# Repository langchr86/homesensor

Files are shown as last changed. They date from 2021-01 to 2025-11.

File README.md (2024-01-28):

homesensor
==========



Air quality sensor designed for battery operation and central data collection in HomeAssistant.

Introduction
------------

This project contains all things needed to setup e.g. a sensor grid for monitoring
temperature, humidity and CO2-levels in several rooms in your home and maybe outside.

The sensors are built from scratch with an `ESP32` as compute unit
and a sensirion `SHTC3` for temperature and humidity monitoring.
For additional CO2-level measurement a sensirion `SCD30` can be used.
The software is based on `platform-io` and is therefore easy to build and deploy.

The sensor data is sent via W-LAN and MQTT protocol to `home assistant` on the backend server.
Home assistant is at first place a home automation system.
But one part of automation is to collect data from sensors.
We therefore use this mechanisms and the corresponding Web-UI
to have a flexible way to store and visualize the collected data.

A very similar but more generic project is [ESPHome](https://esphome.io/)

Getting started
---------------

The whole project consists of the following parts:

* [Backend Software](backend/)
* [Hardware](hardware/)
* [Device Software](software/)

See the linked sub-pages for further instructions.

Usage
-----

<p float="left">
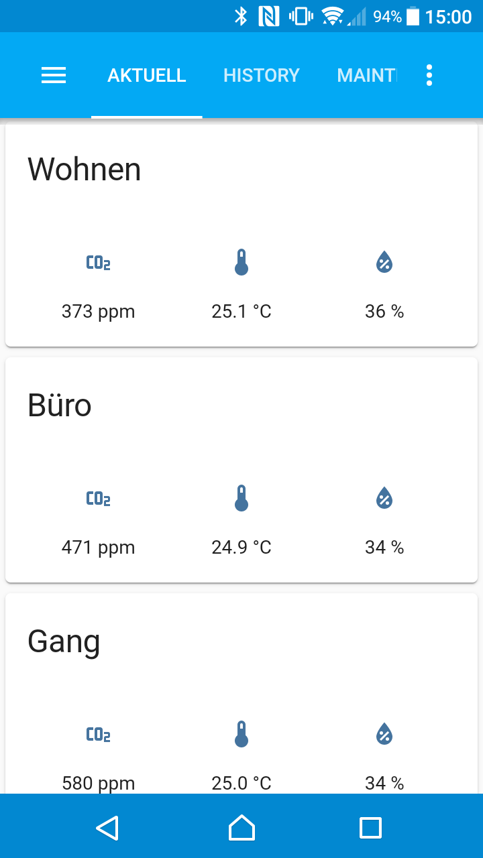
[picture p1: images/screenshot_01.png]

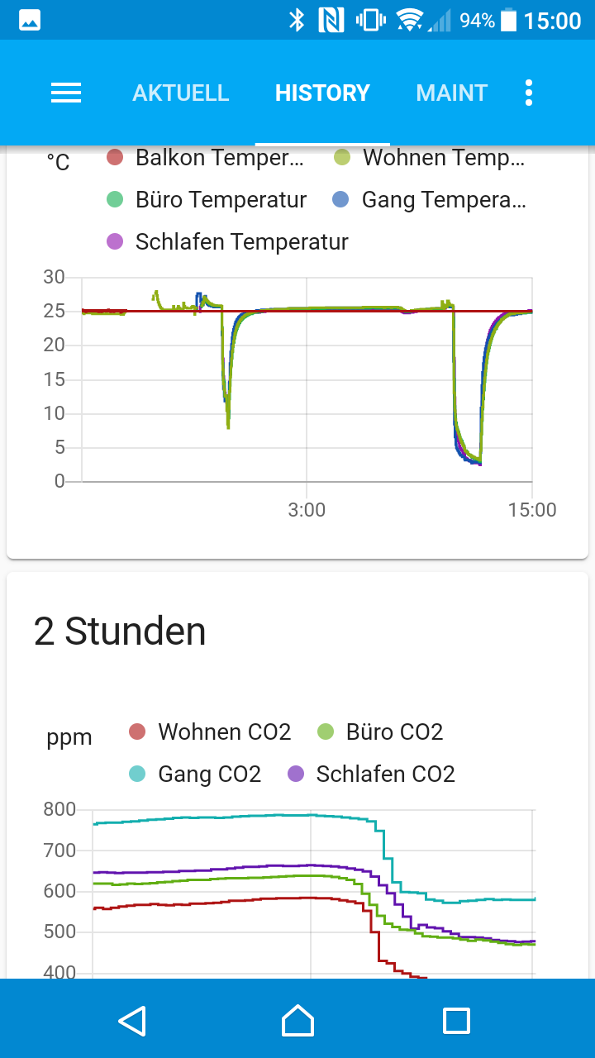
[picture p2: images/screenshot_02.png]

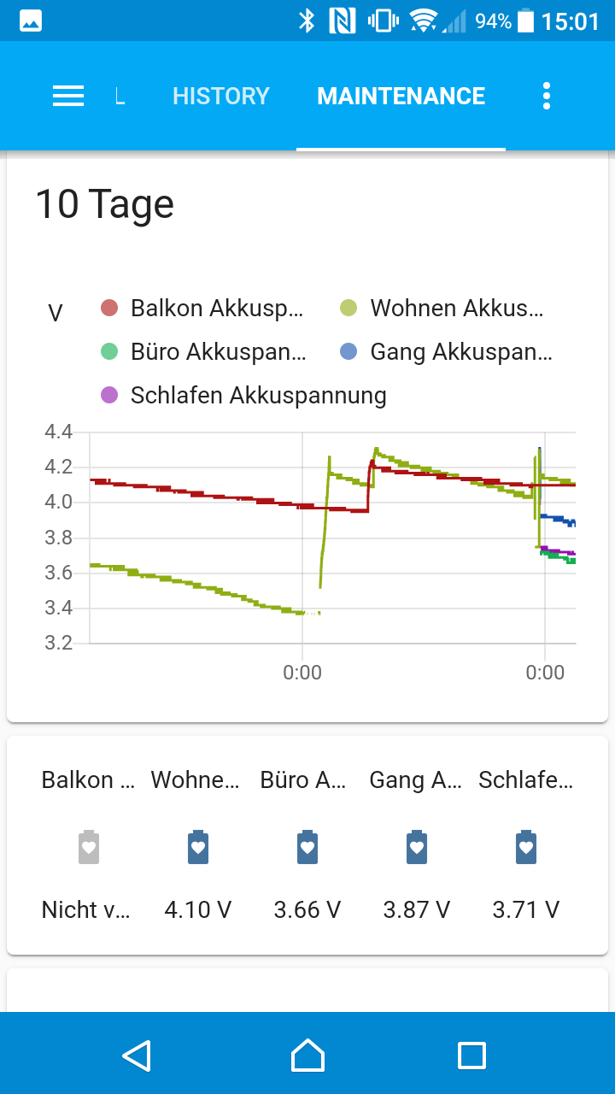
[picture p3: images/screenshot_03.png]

</p>

### Indoor - SCD30

<p float="left">
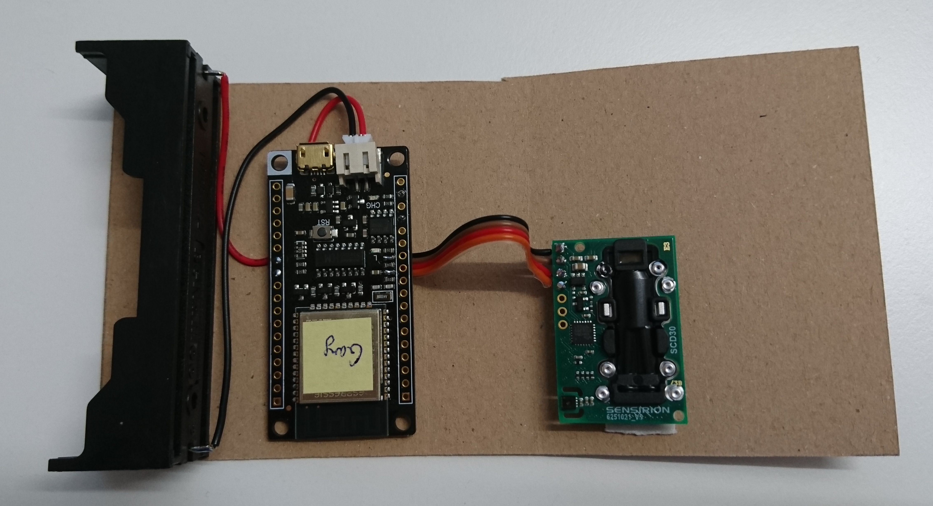
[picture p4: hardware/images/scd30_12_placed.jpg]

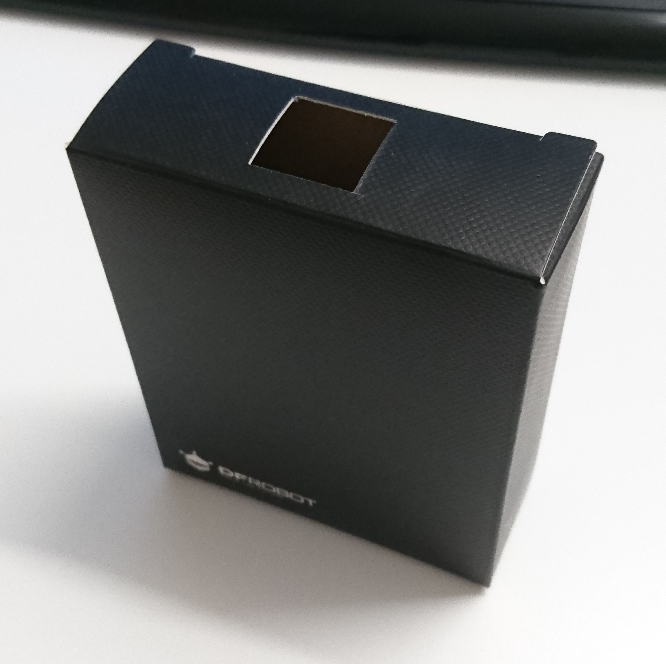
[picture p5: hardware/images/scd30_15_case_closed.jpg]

</p>

### Outdoor - SHTC3

<p float="left">
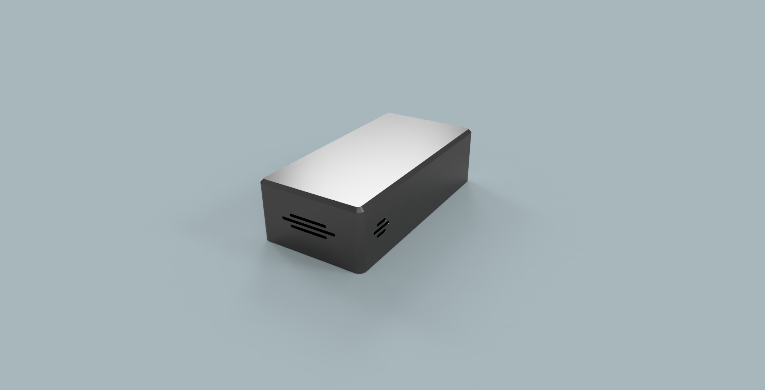
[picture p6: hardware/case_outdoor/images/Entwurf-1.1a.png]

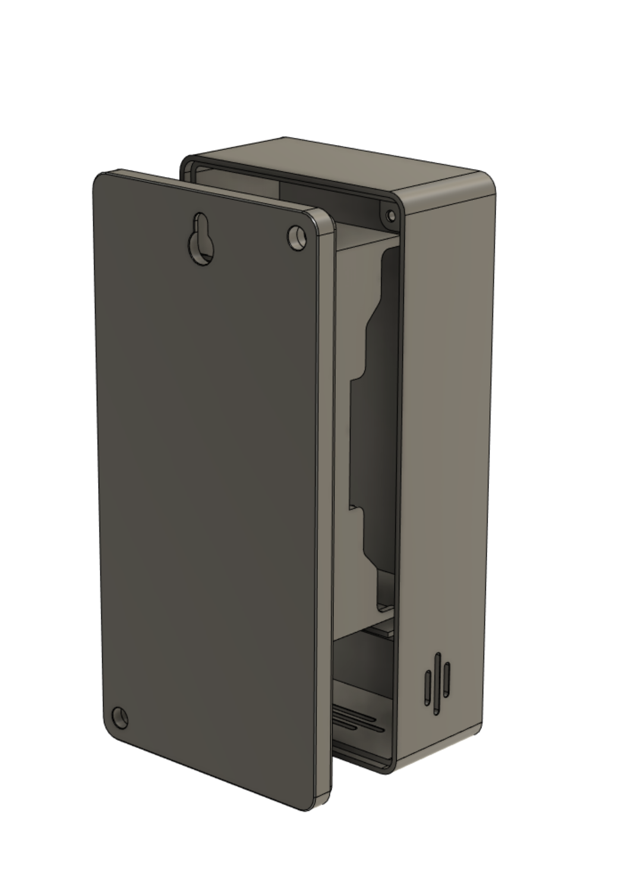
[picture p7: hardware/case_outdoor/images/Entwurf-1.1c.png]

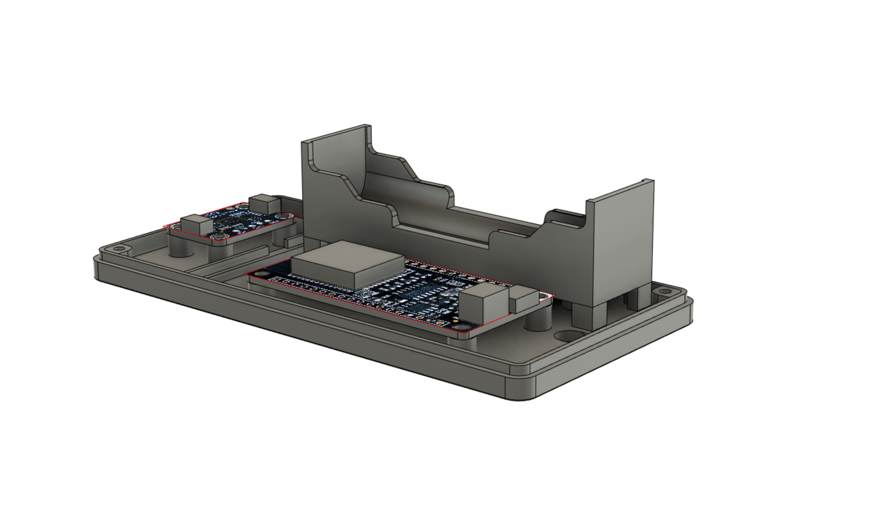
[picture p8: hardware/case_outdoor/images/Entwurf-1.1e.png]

</p>

License
-------

MIT

Versioning
----------

There exists no version numbers, releases, tags or branches.
The master should be considered the current stable release.
All other existing branches are feature/development branches and are considered unstable.

Author Information
------------------

Christian Lang

[lang.chr86@gmail.com](mailto:lang.chr86@gmail.com)

Credits
-------

* 3D printed Case: [langdesign.ch](https://langdesign.ch/)

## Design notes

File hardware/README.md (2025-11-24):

Device production
=================

Bill of Material
----------------

* DFRobot Firebeetle ESP32: [1738-1302-ND](https://www.digikey.ch/product-detail/de/dfrobot/DFR0478/1738-1302-ND/7398878)
* Adafruit breakout board: Sensirion SHTC3: [1528-4636-ND](https://www.digikey.ch/product-detail/de/adafruit-industries-llc/4636/1528-4636-ND/12504001)
* Sensirion SCD30: [1649-1098-ND](https://www.digikey.ch/product-detail/de/sensirion-ag/SCD30/1649-1098-ND/8445334)
* 18650 Battery holder: [BH-18650-PC-ND](https://www.digikey.ch/product-detail/de/mpd-memory-protection-devices/BH-18650-PC/BH-18650-PC-ND/3029216)
* JST 2pin power connector: [1528-1126-ND](https://www.digikey.ch/product-detail/de/adafruit-industries-llc/261/1528-1126-ND/5353586)
* 5W USB-Micro power supply: [VFL05US050-EU-UB](https://www.digikey.ch/de/products/detail/xp-power/VFL05US050-EU-UB/25320746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)

Firebeetle preparation
----------------------

First we have to prepare the CPU board.
The main thing we have to do is to enable the input voltage measurement.
For this we have to short two prepared jumbers or place 0Ohm resistors.
Those are the `R10` and `R11` on the board.

<p float="left">
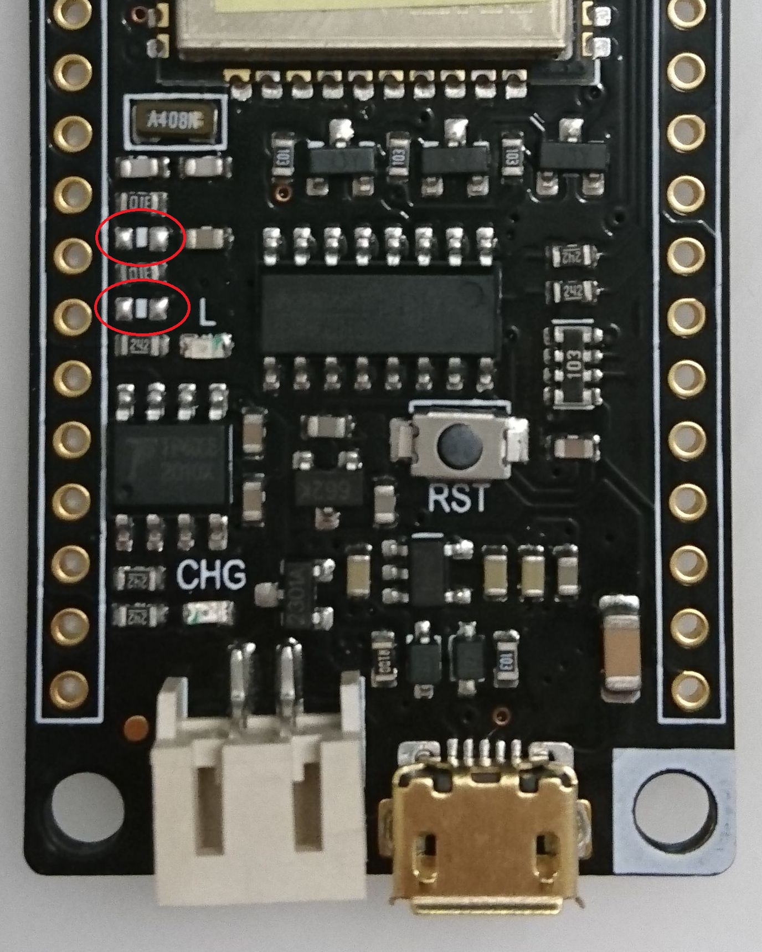
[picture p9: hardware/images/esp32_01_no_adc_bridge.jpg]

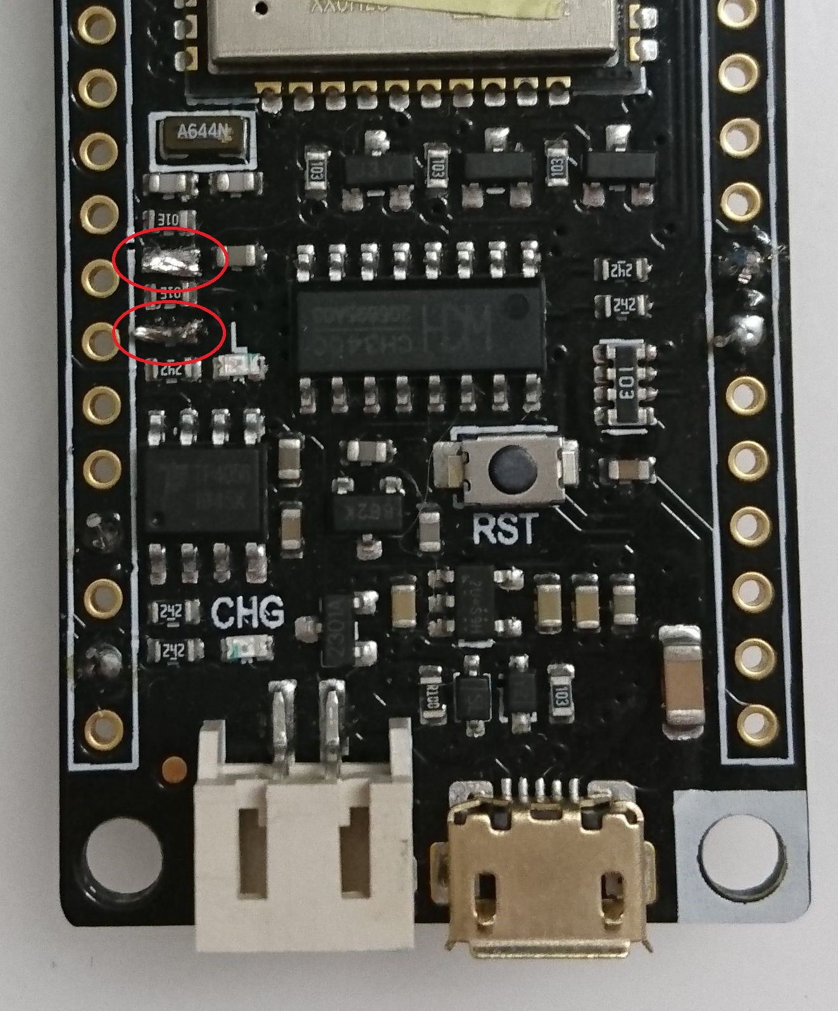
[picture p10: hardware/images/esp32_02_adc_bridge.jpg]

</p>

Battery
-------

A li-ion battery is used as power source for the device.
The intergrated charge circuit does charge to a fixed voltage of 4.2 V.
This may be too much for usual li-ion cells.
Ensure that you use a battery that is not damaged by this higher voltage
or even use a more compatible lipo battery.

Indoor sensor
-------------

First correctly wire the sensor to the CPU board.

<p float="left">
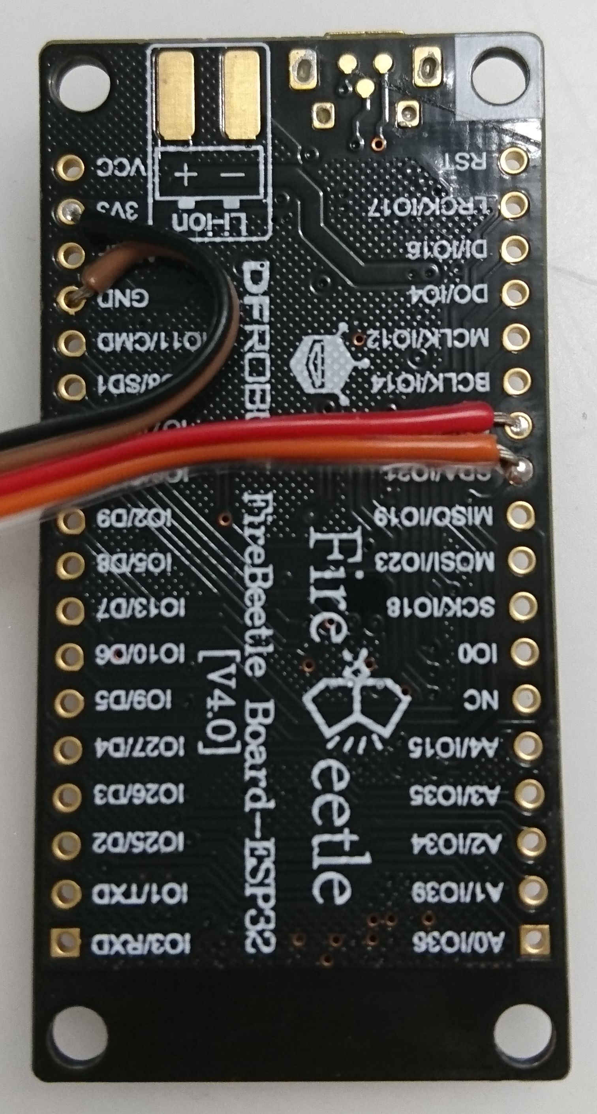
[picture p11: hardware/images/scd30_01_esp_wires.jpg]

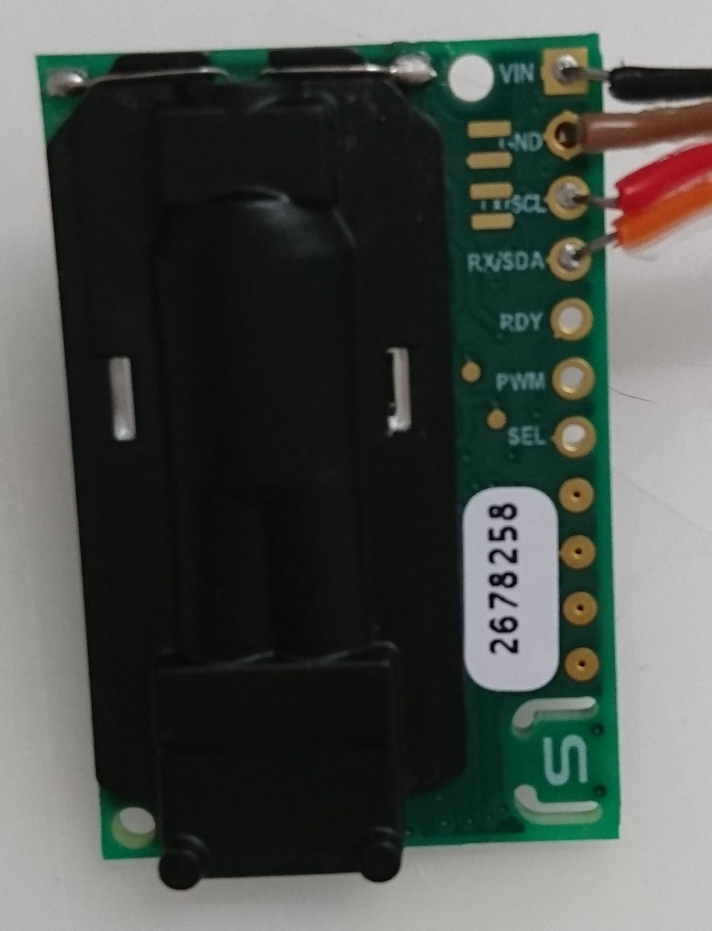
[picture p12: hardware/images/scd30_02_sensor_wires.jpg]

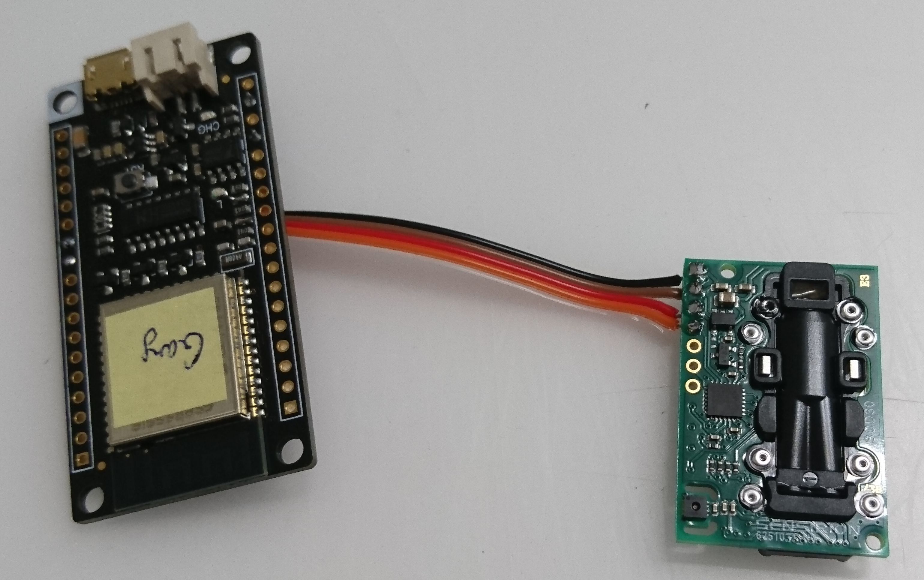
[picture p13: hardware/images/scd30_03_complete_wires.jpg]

</p>

We use the box in which the ESP32 was delivered as a case.
This has a good size and is good enough for indoor usage.
The electronic parts are assembled to an additional cardboard.

<p float="left">
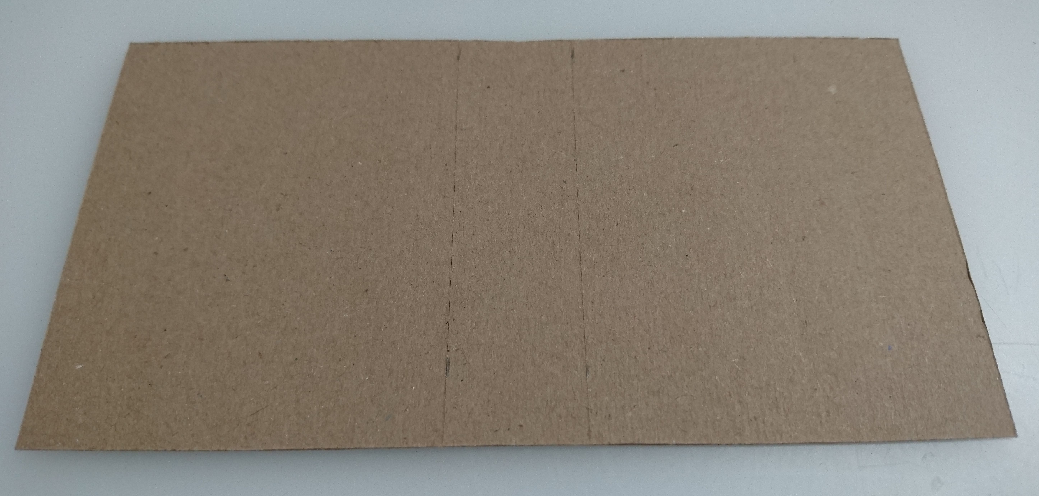
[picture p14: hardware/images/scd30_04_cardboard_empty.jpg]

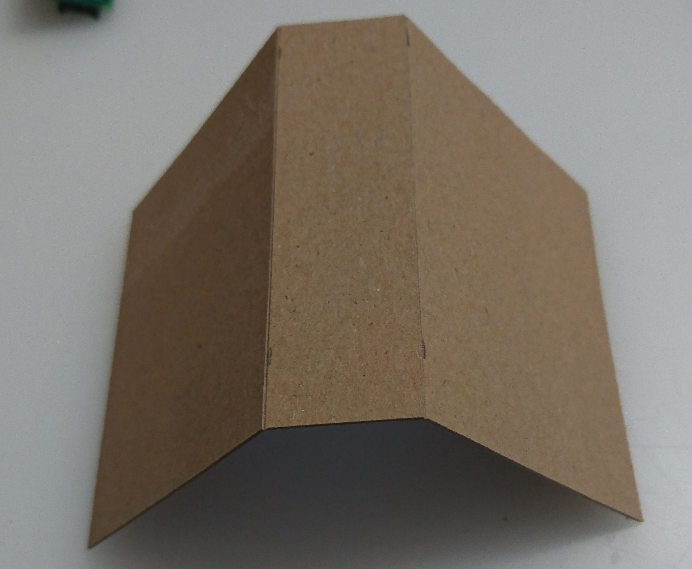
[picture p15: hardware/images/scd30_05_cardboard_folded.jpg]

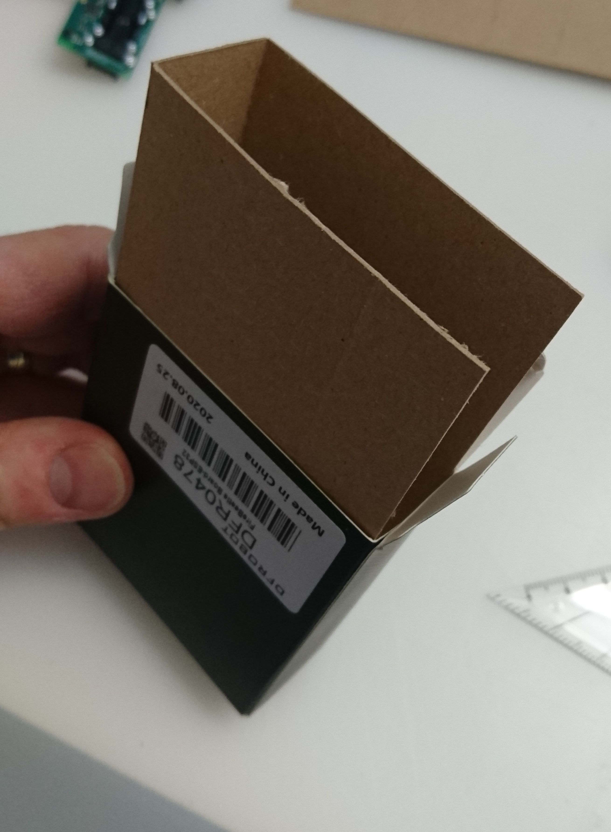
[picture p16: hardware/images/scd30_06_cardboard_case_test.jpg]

</p>

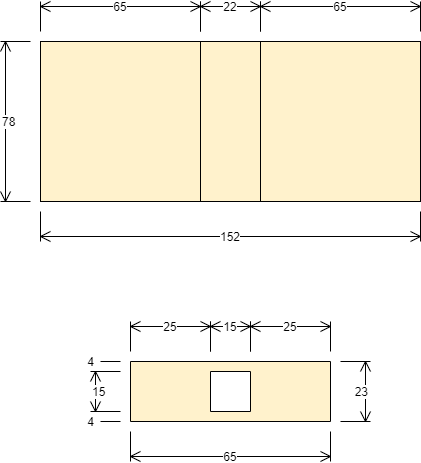
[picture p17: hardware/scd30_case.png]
Case plan


The box need to have air holes on both lids to enable air flow.

<p float="left">
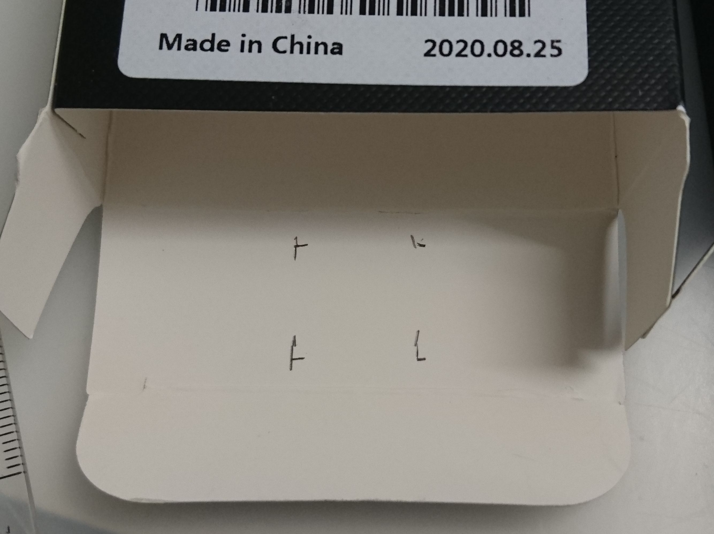
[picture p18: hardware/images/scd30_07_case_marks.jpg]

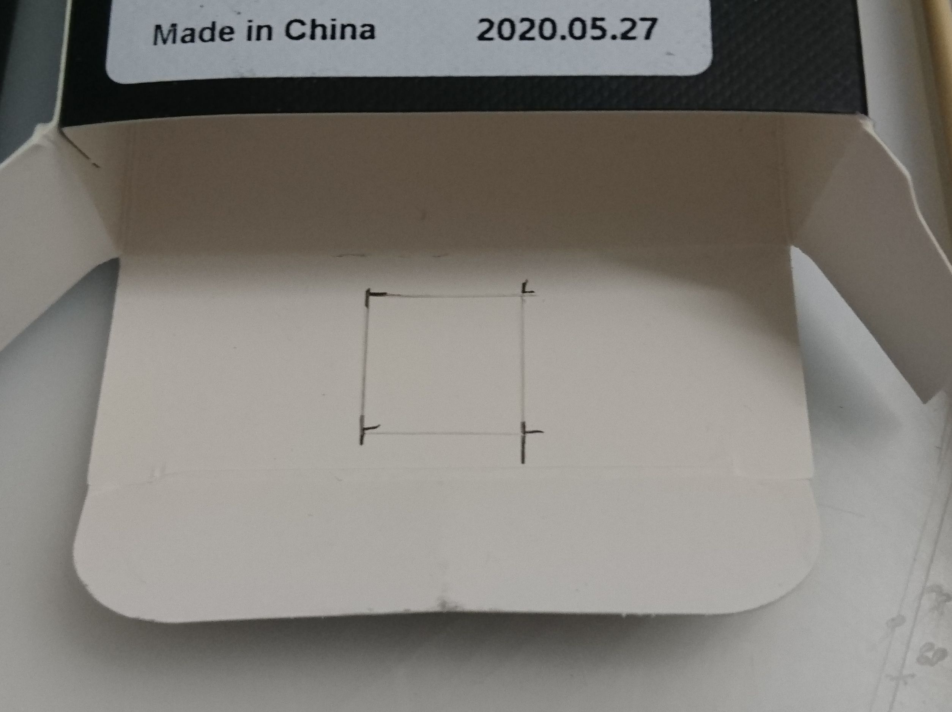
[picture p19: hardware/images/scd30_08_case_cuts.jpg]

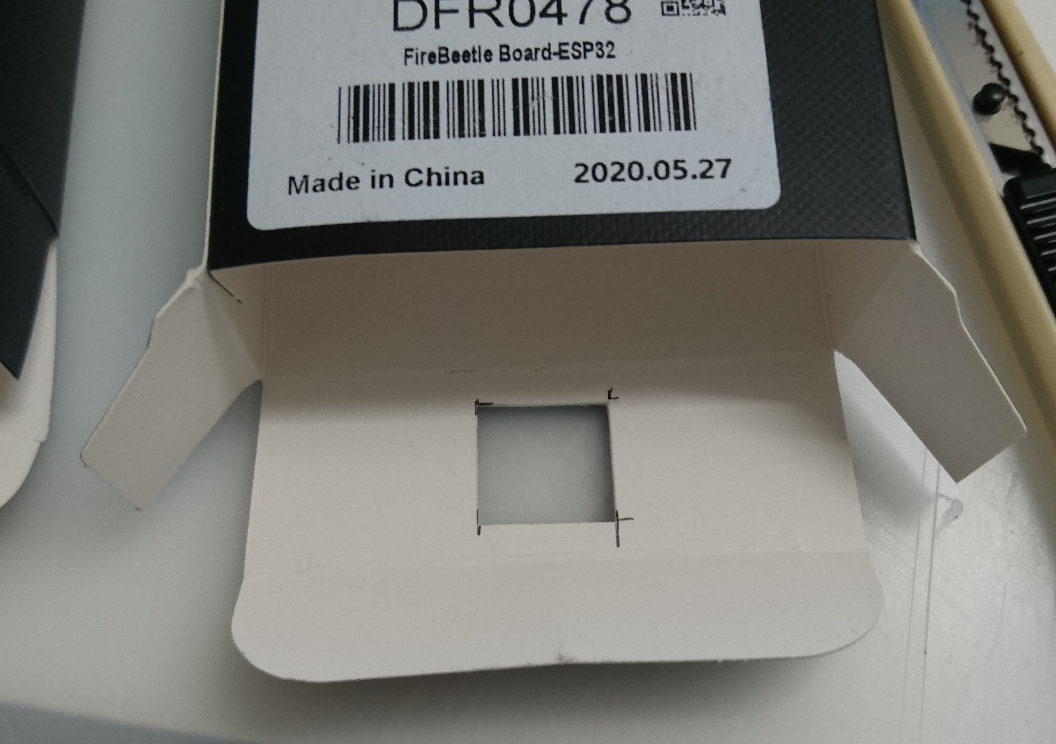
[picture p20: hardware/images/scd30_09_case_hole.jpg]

</p>

The eletronic parts are attached to the cardboard with adhesive tape.

<p float="left">
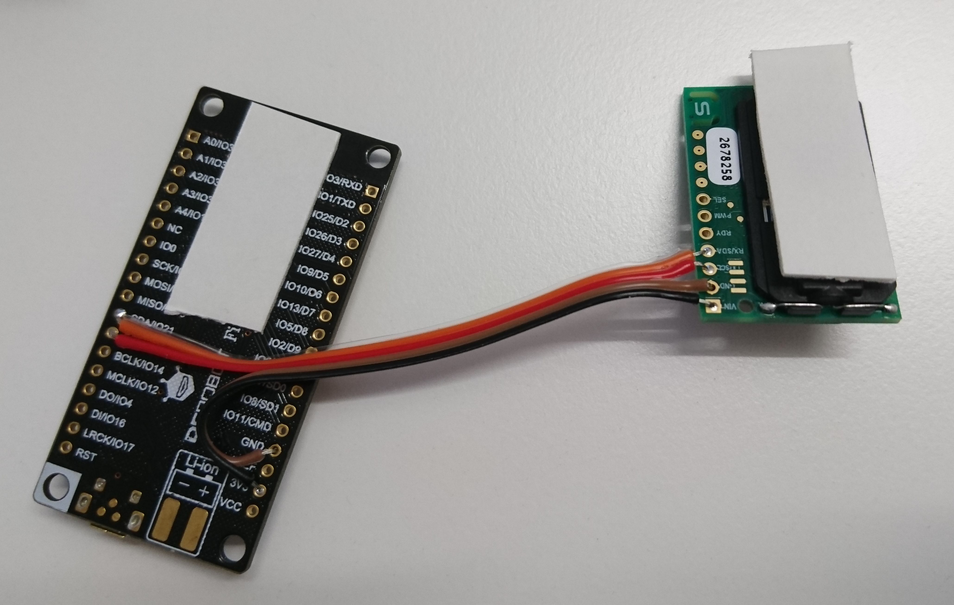
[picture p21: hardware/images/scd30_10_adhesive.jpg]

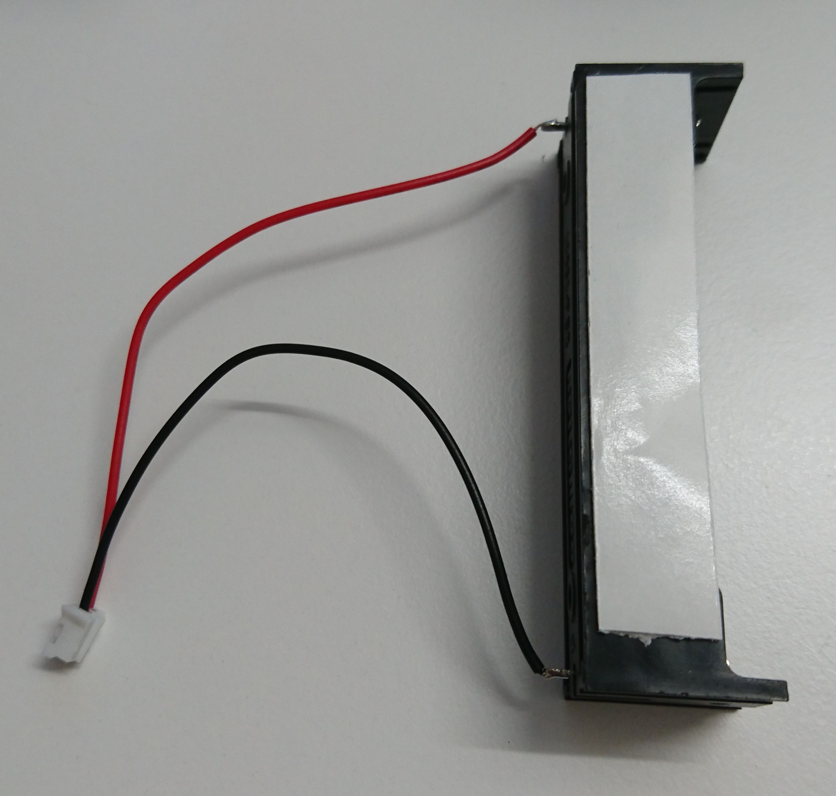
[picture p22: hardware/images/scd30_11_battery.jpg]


</p>

The cardboard can then be inserted in the box.

<p float="left">
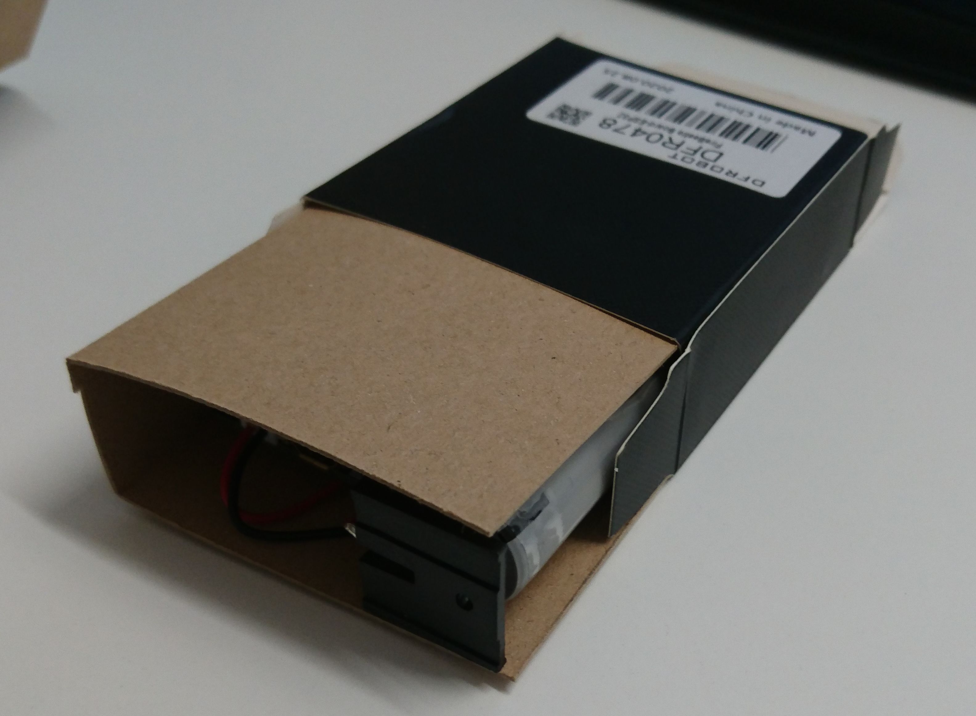
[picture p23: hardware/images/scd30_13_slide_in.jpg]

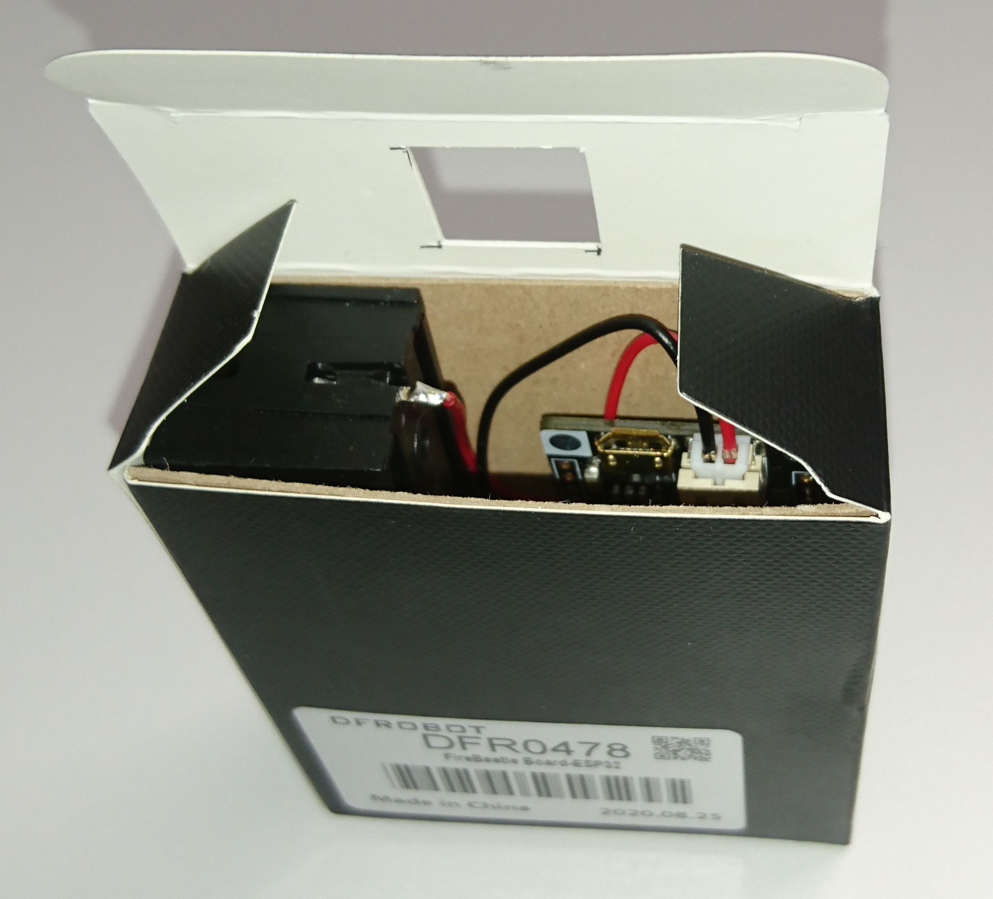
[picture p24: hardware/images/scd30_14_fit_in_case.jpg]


</p>

Outdoor sensor
--------------

If you want to have as less power consumption
and most importantly no always glowing LED
you have to remove it from the Adafruit board.

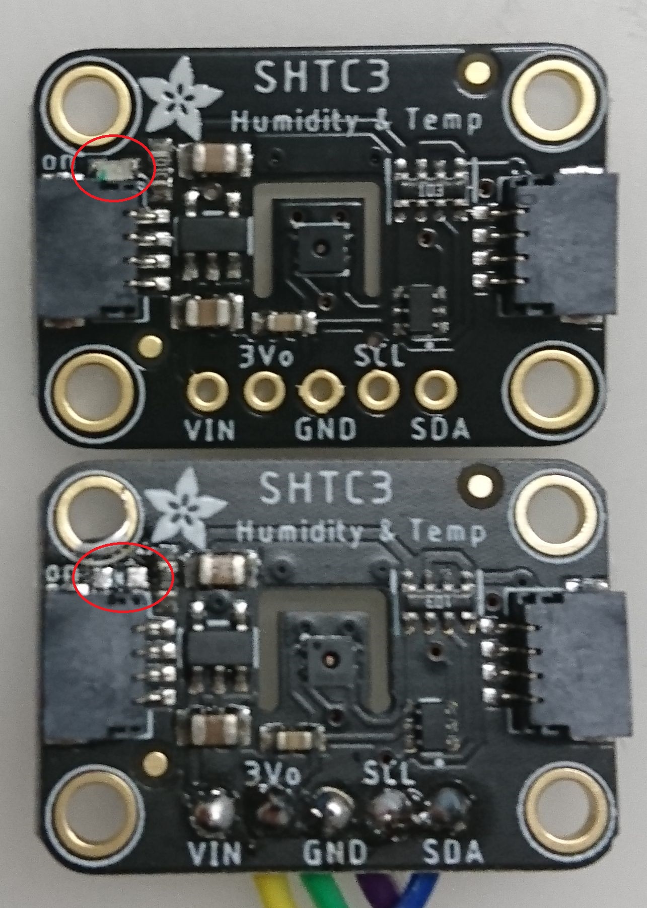
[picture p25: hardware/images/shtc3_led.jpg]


**ToDo: cabling/images**

We use a 3D printed case for the outdoor sensor
because of the weather influence.
The case is designed for 0.2mm nozzle diammeter and PLA.
Usually temperature sensors have white or other light colored cases.

<p float="left">



</p>

**Not yet printed/tested**

**Images are no longer up-to-date with the real model data. Will be updated after real printing test.**

The corresponding files are located under `case_outdoor/`.
To ensure longevity of the screw holes we use special plastic screws.
More information for those
[SCHRIEVER STS Senkkopf Schrauben T KN 1041 Stahl znb 1227](https://www.sfs.ch/de/Befestigungstechnik/Blech-%2C-Bohr-%2C-Gewindefurchschrauben/Gewindefurchende-und-gewindeschneidende-Schrauben/Gewindefurchschrauben-f%C3%BCr-K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)
can be found in the datasheet in the top level `documents` folder.

~~~~~~
d1 = 2.2
d2 = 3.8
t = 6
Antrieb = T6
Löcher = 1.85
~~~~~~

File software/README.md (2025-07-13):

Software
========

Getting started
---------------

The simplest way to work with PlatformIO is to setup Visual Studio Code and the corresponding extension.
See: [platformio.org/install/ide?install=vscode](https://platformio.org/install/ide?install=vscode)

After the installation of the IDE the project should be cloned with git.
Open the sub folder `software` in vscode.
Now you start compilation and flashing with the control elements in the bottom status line of vscode.

If the serial adapter of the ESP is not detected you may need the corresponding driver.
Usually the one in the `driver` subfolder is working on Windows 10.

Configuration
-------------

The default state of the code will not work because it contains no credentials for your Wifi network
and also the IPs should be changed in most cases.
All those things that should/can be configured are contained in the file `src/config.h`.

Things that almost always need to be adapted to the specific environment are:

* Wifi credentials
* Home assistant IP
* Network gateway/mask
* MQTT credentials and port (can be left as is if the default empty fields were used at setup of home assistant)

**Ensure that you never push commits to remotes that contain your private credentials!**

After those central parts the individual sensor devices can be added to the device list.
To be able to have a simple deployment process all devices can be added
and at deplyoment only the `kDeviceConfigIndex` needs to be adapted to switch to different sensor devices.

Home assistant visualization
----------------------------

After the corrected credentials etc. has been set and a correctly built sensor has been flashed
it should start to send messages after a few seconds to the home assistant server.
A correct startup is visualized by fast blinking (500ms interval) blue LED after hardware initialization.
Because the sensor devices use auto configuration
they should automatically appear under `devices` in home assistant.
Auto configuration happens at first start, after multiple consecutive failed boots
or if configured with `kHaConfigInterval` in regular intervals.
Then they can be used to setup data visualizations on `lovelace dashboards` in home assistant.

<p float="left">
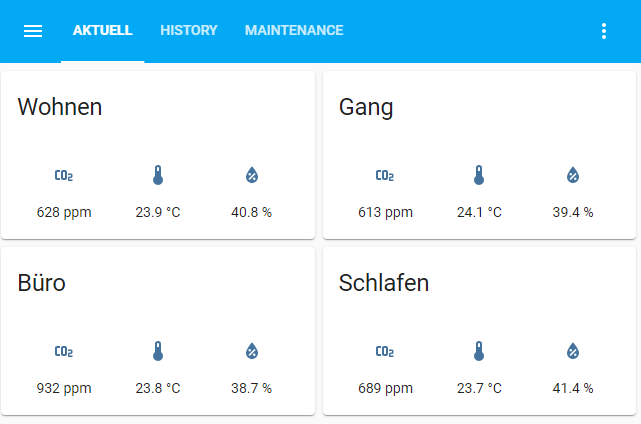
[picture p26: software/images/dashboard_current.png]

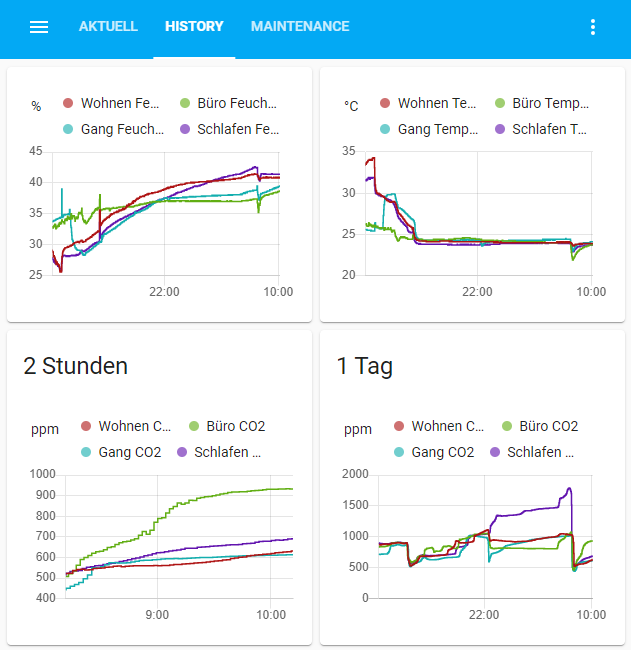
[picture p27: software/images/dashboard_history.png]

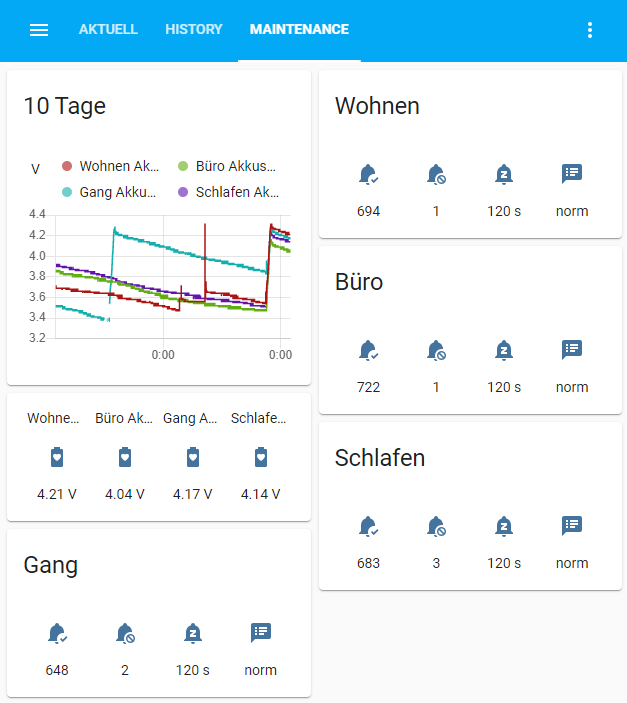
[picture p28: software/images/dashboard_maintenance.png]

</p>

The sent data fields are grouped to sensor devices.
If you defined a sensor with the name `buero`
you will see the corresponding data entities named like `sensor.buero_co2`.

There exists multiple categories of data fields that are sent to home assistant:

* sensor data: temperature, humidity, CO2
* battery information: voltage, approx. capacity
* debug information: boot count, readout interval, mode string

To see all sent fields and their configuration
you can enable logging (see development section)
and watch the first boot.
The serial output will show the exact JSON data that is sent via MQTT to home assistant.

Battery Operation
-----------------

This project does focus on battery operation.
Therefore a computing platform has been choosen that supports low power consumption
and integrated charging possibilities.
Charging is enabled by simply connecting a power source to the micro USB connection.
The charging is visualized by the red LED.
After charging is complete the LED will switch off.

**Attention:** Measurements will be influenced by the heat generated by the charging circuit.

Low power operation is realized by going to deep sleep after each sensor readout and data sending.
The power consumption of the CPU during deep sleep is about 10 uA.
Sadly the more relevant consumers are the sensors.
Where the SHTC3 board does increase the consumption to about 100 uA.
The SCD30 is even more demanding and increases the consumption up to about 4-6 mA during sleep.
The deep sleep duration can be adjusted by `kDefaultReadoutInterval` in `src/config.h`.

During sensor readout, processing and data sending, the consumption increases to 150 mA at maximum.
This high demand is mainly triggered by the Wifi connection setup and data sending.
The whole awake state usually needs about 2-3 seconds.
In case of the SCD30 it can take even longer.
This is because of the not exactly synchronized readout interval and sensor read.

With those numbers we can approx. calculate a possible runtime with one battery charge:
[Battery life calculator](http://www.of-things.de/battery-life-calculator.php).
Measured runtime of sensors with readout interval of 2 minutes and a battery of 2500 mAh capacity are:

* SCD30: 2 weeks
* SHTC3: more than 1 month

### Increase readout interval during problems

The configured readout interval can change during runtime because of different software problems.
Main source of such readout aborts are no sensor data or no Wifi connection.
In all those cases the device aborts the readout and goes to sleep again.
After the third consecutive aborted wake up the readout interval is doubled.
This is to reduce the failing tries
and therefore also reduce power consumption.
This helps to increase battery lifetime in cases where it is useless to try in short intervals.
This may be helpfull e.g. if a Wifi hotspot is regularly not available (e.g. during night).
The readout interval is increased to a maximum of `kMaxReadoutInterval`.
It is reset after a successfull readout.

### Low power mode

Because the li-ion battery is sensible to low discharge
the device does reduce power consumption if the battery voltage goes under 10% of maximum capacity.
This is checked in the `Sleep` function in `src/main.cpp`.
In such cases the readout interval goes directly to maximum of `kMaxReadoutInterval`.
This is also helpfull to notify the user about low power
because the sensor data will become sparse.
That behavior is triggered because of the maximum readout interval is much longer
than the expiration time of individual sensor data in home assistant.

Power supply operation
----------------------

You should remove the battery
if you want to operate the sensor with a power supply constantly connected.
This is because measurements will be influenced by the heat generated by the charging circuit.

In addition the temperature measurement may differ because of different voltage levels given to the sensor.
Therefore you may need to adapt the temperature offset/calibration mentioned below in the "Known issues" section.

Calibration
-----------

### CO2

The measurement of CO2 concentration is no simple task.
This is reflected in the high price of such sensors.
In addition such sensors need to be calibrated from time to time and especially before first commissioning.
The used SCD30 sensor has various mechanisms to reduce sensor drift over time.
But even we do only need to calibrate the sensor approx. once a year,
we have to calibrate it at least at first setup.

The software has a special calibration mode for this
that can be started by shorting the GPIO-4 to GND at startup.
This mode can only be enabled during first boot
and is then visualized by the slow blinking (2s interval) blue LED at startup.
The simplest method to do this is to shorten the GPIO and then pressing the hardware reset button on the ESP.
Any kind of wire can be used to shorten the pins.
Even a curved staple will do.

<p float="left">
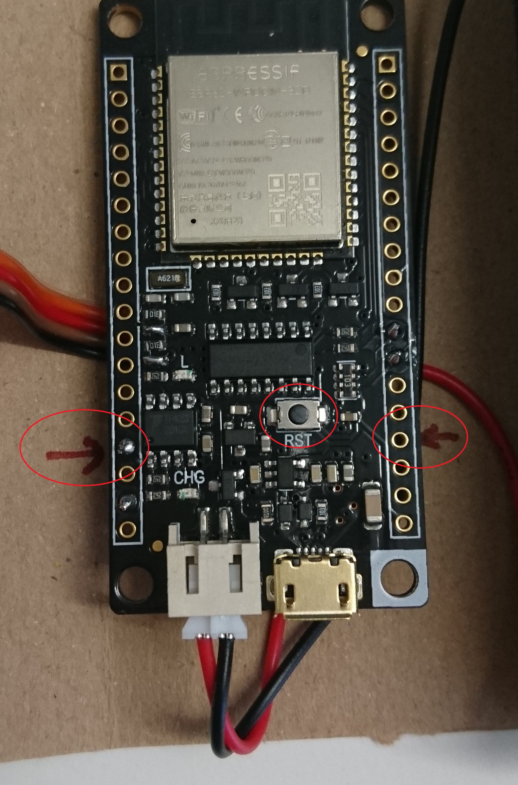
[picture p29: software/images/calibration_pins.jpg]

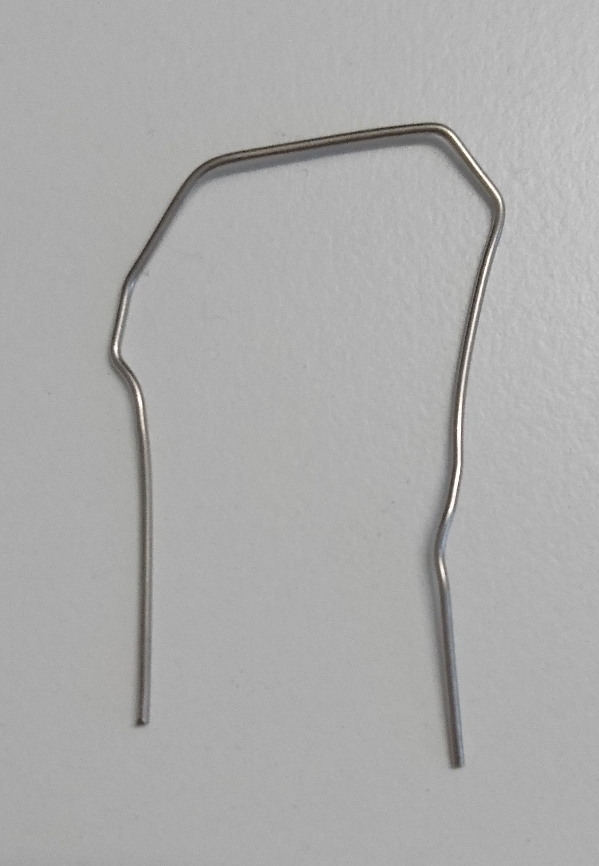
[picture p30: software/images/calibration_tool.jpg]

</p>

After the calibration mode is visualized by the LED, the wire can be removed
and the sensor should be placed in fresh air that has usually normal CO2 concentration of 400 ppm.
The calibration mode is also visualized in the `mode` string sent to home assistant.
The sensor should be left in fresh air until the `calib` string disappears in the mode.
The calibration time depends on the readout interval.
For intervals bigger than 1 minute it is 10 times bigger than the configured interval.
For smaller intervals it is 10 minutes.

Calibration parameters are stored in the sensor itself and not in the ESP.
Therefore even after powerloss or flashing of new software no recalibration is needed.

### CO2 Autocalibration mode

No manual calibration is needed if you operate the sensor in an environment with constant support of fresh air.
The sensor datasheet explains this further:

> The correct application of ASC requires the SCD30 to be regularly exposed to air with CO2 concentration = 400 ppm,
> as is the case in well ventilated buildings over night without human presence.

This `ASC` mode can be enabled by changing the parameter to the call of `setAutoSelfCalibration` to `true` (`src/sensors/scd30.cpp`).

Development
-----------

We can use the already setup vscode/platformio environment to work on new features or fix bugs.
To have more insights what is happening the serial log output can be used.
The logger is enabled by removing the following line in `src/utils/logger.h`

~~~~~~
#define LOG_DISABLE
~~~~~~

This enables all the loggings.
The log level can be changed by the following line in `src/main.cpp` accordingly

~~~~~~
logger.SetMaxLevel(LOG_DEBUG);
~~~~~~

To see the log output we need to have the ESP connected via USB and start the `PlatformIO: Monitor` task via `Terminal -> Run Task`.
The logger gives not only simple `printf` style messages (which can have aribtrary arguments formated in)
but also timestamps of each log statement.
Those timestamps relates to the startup time point and do not represent real wall time.

Known issues / future features
------------------------------

* Values that cannot be calibrated individually (only globally) and therefore may differ a little:
  * battery voltage (`src/sensors/adc.h` -> `max_voltage`)
  * battery min/max levels (`src/sensors/battery_calculation.h` -> `low_voltage`/`high_voltage`)
  * temperature SHTC3 (`src/sensors/shtc3.cpp` -> `SetCalibration(...)`)
  * temperature SCD30 (`src/sensors/scd30.cpp` -> `setTemperatureOffset(...)`)
  * humidity (could use `SetCalibration` of `SensorBase` similar to already used in SHTC3)
* SCD30 sensor data may not available when CPU awakes. This could be improved by:
  * better synchronize readout cycles with sensor readout (deep sleep duration should be: readout interval - awake duration)
  * do not depend on sensor data ready at each wake up but send no or old data instead and go directly to sleep
* Wifi credentials are stored in raw data in the ESP flash memory.
  Those could theoretically be extracted from this memory if the device is stolen.
  This could be fixed by using encrypted storage.

License
-------

See top level [README.md](../README.md).

The integrated and improved libraries are the following:

* [scd30 / SoftWire](https://github.com/paulvha/scd30) -> MIT
* [sht30](https://github.com/sparkfun/SparkFun_SHTC3_Arduino_Library) -> GPL v3

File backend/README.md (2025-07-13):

Backend
=======

Home Assistant is used to collect the measured data of the sensors.

The easiest and most future prove way is to follow one of the tutorials provided by Home Assistant itself:
[Home Assistant - Installation](https://www.home-assistant.io/installation/).

Because the sensor is using MQTT as data protocol
we need to install the MQTT Integration in Home Assistant: [](https://www.home-assistant.io/integrations/mqtt/).
If Home Assistant was installed with HA-OS we also need to install the MQTT Broker
as Home Assistant add-on: [Mosquitto broker](https://github.com/home-assistant/addons/blob/master/mosquitto/DOCS.md)

Using Ansible
-------------

All information below can be used to setup docker and HA by using Ansible.
But this is only recommended for advanced users!

The ansible playbook can install the needed docker containers on any linux system.
In addition a `Vagrantfile` is provided that setups a virtualbox VM for development purposes.

Setup on existing server
------------------------

First we have to ensure that ansible is installed.

~~~~~~
apt install ansible

# or
apt install software-properties-common
apt-add-repository ppa:ansible/ansible
apt update
apt install git ansible

# or
apt install python3-pip
pip3 install ansible
~~~~~~

For the real installation you need a linux server that has a running `docker-compose` installation.
You can either use the existing role to install `dockerce` / `dockerio`
or install with your package manager e.g. `apt install docker.io docker-compose`
or use some other way e.g. [github.com/geerlingguy/ansible-role-docker](https://github.com/geerlingguy/ansible-role-docker).

You then can clone this repo on your server and run the script `run_local.sh`.
Or you can include the `homeassistant` role in your own ansible playbook for your server.

Now you can configure Home Assistant.

Setup VM for development purposes
---------------------------------

The vagrant configuration is ready to be used to setup a complete VM with Home Assistant.
In addition all ports needed are already forwarded and can be accessed on the local machine.

Install vagrant and virtualbox and start the VM creation with:

~~~~~~
cd homesensor/backend
vagrant up
~~~~~~

Because the sensors are external devices the MQTT port `1883` needs to be reachable from outside the machine.
Add a corresponding incoming rule in the firewall.

The Web-GUI is usually accessed in a browser on the local machine.
If this needs to be accessible from another machine the port `8123` needs to be allowed in the firewall.

If you need later to manipulate the vagrant VM the following commands are useful:

~~~~~~
vagrant halt
vagrant destroy -f
vagrant provision
vagrant up --provision
~~~~~~

Now you can configure Home Assistant.

Configure Home Assistant
------------------------

You can now configure Home Assistant
after installing the `homeassistant` and `eclipse-mosquitto` (MQTT) container on your server host.

* Login to: `<YOUR_HOMEASSISTANT_IP>:8123` with your web browser.
* Create a user account.
* Name your Home Assistant installation. E.g: `homesensor-backend`. And define your location.
* At the next page your asked to select integration services to install. Search and install the `MQTT` integration.
  Use `localhost` for server IP and no user and no password. The port should be kept at the default `1883`.
  Enable the flag for the search function.
* Finish the configuration and re-login at the same URL again with your defined user and password.

> Note: We do not define any MQTT credentials to work in anonymous mode.
> You can define credentials but then also need to configure those in the sensors used.

Now you can flash your sensor boards.
They should automatically appear as device/entity in your Home Assistant lovelace board.

Additional Home Assistant configuration
---------------------------------------

As defined in the `docker-compose.yml` the Home Assistant configuration is mounted to the host file system.
To configure Home Assistant manipulate the automatically created `configuration.yaml`.
E.g. by changing the history duration from 10 (default) to 28 days:

~~~~~~
recorder:
  purge_keep_days: 28
~~~~~~

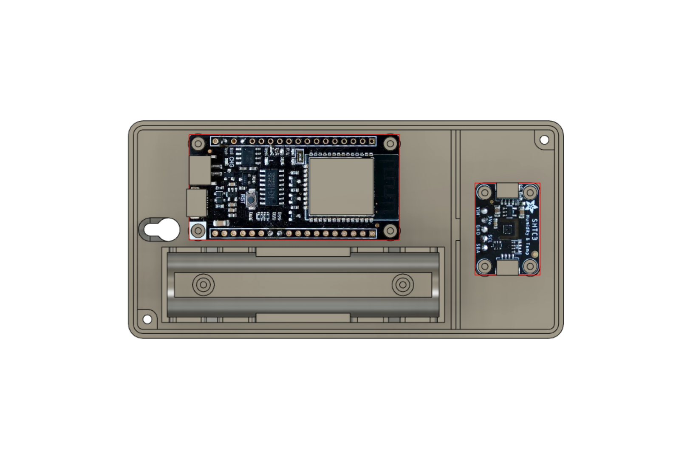
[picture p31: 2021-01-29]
hardware/case_outdoor/images/Entwurf-1.1b.png

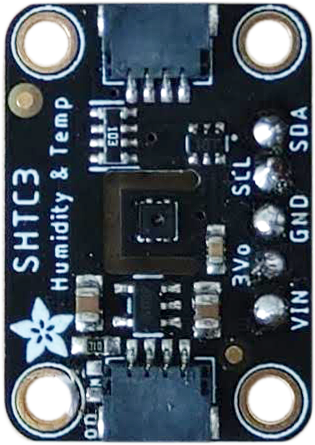
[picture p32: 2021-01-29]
hardware/case_outdoor/images/Sensor.png

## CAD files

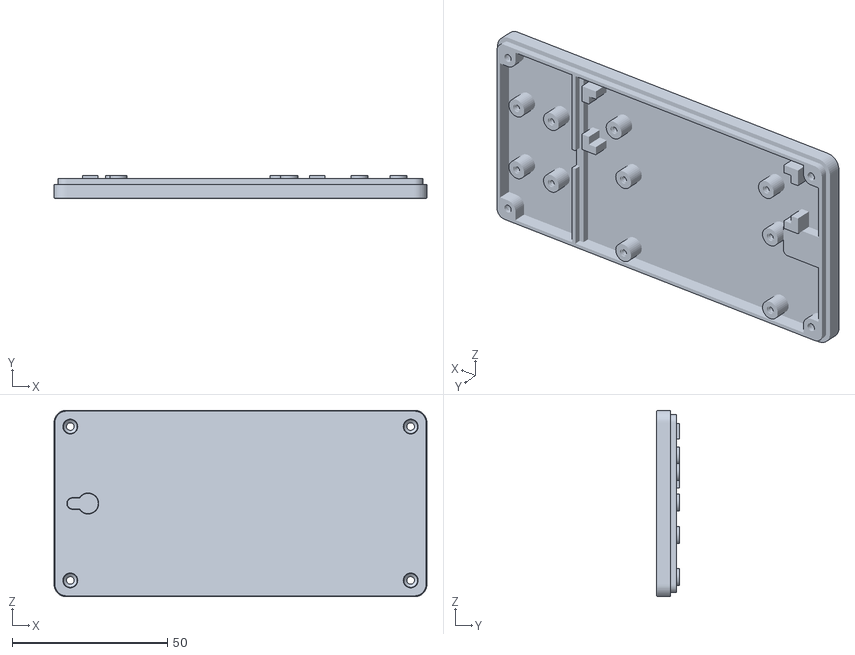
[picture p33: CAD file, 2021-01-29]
hardware/case_outdoor/Boden.stl
120.0 x 7.50 x 60.0

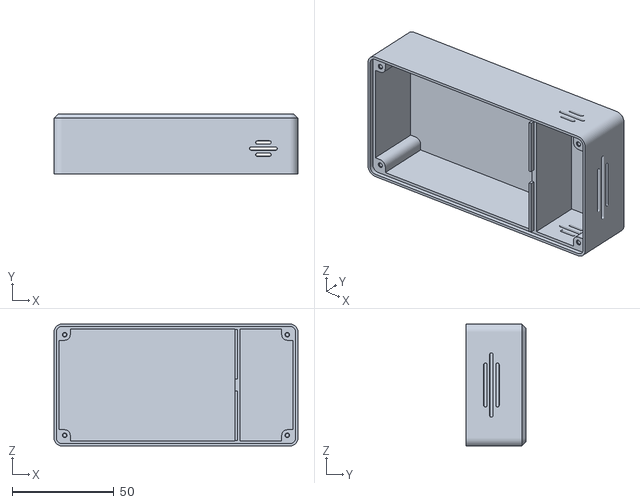
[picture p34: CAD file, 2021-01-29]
hardware/case_outdoor/Deckel.stl
120.0 x 29.5 x 60.0

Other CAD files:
hardware/case_outdoor/Gehaeuse.f3z

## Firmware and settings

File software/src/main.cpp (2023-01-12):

#include <string>

#include <Arduino.h>

#include <SoftWire.h>

#include "communication/connection.h"
#include "infrastructure/device_factory.h"
#include "sensors/adc.h"
#include "utils/led.h"
#include "utils/logger.h"
#include "utils/power.h"

#include "config.h"

std::shared_ptr<SensorInterface> sensor = nullptr;

RTC_DATA_ATTR bool sensor_hardware_initialized = false;
RTC_DATA_ATTR size_t boot_count = 0;
RTC_DATA_ATTR size_t failed_boot_count = 0;
RTC_DATA_ATTR size_t failed_consecutive_boots = 0;
RTC_DATA_ATTR size_t ha_config_count = 1;
RTC_DATA_ATTR std::chrono::seconds readout_interval = kDefaultReadoutInterval;
RTC_DATA_ATTR std::chrono::seconds max_readout_interval = readout_interval;

RTC_DATA_ATTR bool calibration_active = false;
RTC_DATA_ATTR std::chrono::seconds remaining_calibration_time;

bool InitWire(Logger *logger, TwoWire *wire)
{
  wire->begin();
  wire->setClock(kWireSpeedHz);

  return true;
}

void Sleep(Power *power, Logger *logger)
{
  if (sensor->LowPower())
  {
    logger->LogWarning("Force kMaxReadOutInterval because of low power");
    power->DeepSleepNow(kMaxReadoutInterval);
  }
  else
  {
    power->DeepSleepNow(readout_interval);
  }
}

void ErrorHappened(Connection *connection, Power *power, Logger *logger)
{
  if (connection != nullptr)
  {
    connection->Disconnect();
  }

  failed_boot_count++;
  failed_consecutive_boots++;

  if (failed_consecutive_boots > 3)
  {
    readout_interval *= 2;
    failed_consecutive_boots = 0;

    if (readout_interval > kMaxReadoutInterval)
    {
      readout_interval = kMaxReadoutInterval;
    }

    if (max_readout_interval < readout_interval)
    {
      max_readout_interval = readout_interval;
    }

    logger->LogInfo("Increased read out interval to %u seconds", static_cast<int>(readout_interval.count()));
  }

  Sleep(power, logger);
}

void EndWithNoError(Connection *connection, Power *power, Logger *logger)
{
  failed_consecutive_boots = 0;
  readout_interval = kDefaultReadoutInterval;
  connection->Disconnect();
  Sleep(power, logger);
}

void setup()
{
  boot_count++;
  std::string mode = "norm";

  Led::Disable();
  Power power;

  Logger logger("Main");
  logger.SetMaxLevel(LOG_DEBUG);

  static constexpr uint8_t kCalibrationPin = GPIO_NUM_4;
  static constexpr std::chrono::seconds kMinCalibrationTime = std::chrono::minutes(10);
  pinMode(kCalibrationPin, INPUT_PULLUP);
  if (boot_count == 1 && digitalRead(kCalibrationPin) == LOW)
  {
    calibration_active = true;
    remaining_calibration_time = 10 * kDefaultReadoutInterval;
    if (remaining_calibration_time < kMinCalibrationTime)
    {
      remaining_calibration_time = kMinCalibrationTime;
    }
    logger.LogDebug("Initialized sensor calibration");
    Led::FlashFor(std::chrono::seconds(4), std::chrono::seconds(1));
  }

  auto *wire = &Wire;
  if (InitWire(&logger, wire) == false)
  {
    logger.LogError("Failed to initialize Wire connection");
    ErrorHappened(nullptr, &power, &logger);
  }
  logger.LogDebug("Success: InitWire");

  ADC adc(A0);
  adc.SetBitWidth(9);

  Connection connection(kHomeAssistantIp, kMqttPort, kGatewayIp, kSubnetMask, kMqttMaxMessageSize);

  const std::chrono::seconds expire_timeout(3 * kDefaultReadoutInterval);
  DeviceFactory factory(readout_interval, expire_timeout);

  sensor = factory.CreateDevice(config[kDeviceConfigIndex], &adc, wire, &connection, &power);

  if (sensor == nullptr)
  {
    logger.LogError("Failed to create sensor device");
    ErrorHappened(&connection, &power, &logger);
  }
  logger.LogDebug("Success: factory.CreateDevice");

  if (sensor_hardware_initialized == false)
  {
    mode += "+hwinit";
    if (sensor->HardwareInitialization(kDefaultReadoutInterval) == false)
    {
      logger.LogError("Sensor hardware initialization failed");
      ErrorHappened(&connection, &power, &logger);
    }
    sensor_hardware_initialized = true;
    Led::FlashFor();
    logger.LogDebug("Success: sensor.HardwareInitialization");
  }

  if (calibration_active && remaining_calibration_time <= std::chrono::seconds::zero())
  {
    calibration_active = false;
    if (sensor->ForceCalibrationNow() == false)
    {
      logger.LogError("Sensor calibration failed");
      ErrorHappened(&connection, &power, &logger);
    }
    logger.LogDebug("Success: sensor.ForceCalibrationNow");
  }

  if (calibration_active)
  {
    mode += "+calib";
    remaining_calibration_time -= kDefaultReadoutInterval;
  }

  if (sensor->SensorReadLoop() == false)
  {
    logger.LogError("Sensor read out loop failed");
    ErrorHappened(&connection, &power, &logger);
  }
  logger.LogDebug("Success: sensor.SensorReadLoop");

  sensor->SetDebugInfos(mode.c_str(), boot_count, failed_boot_count, max_readout_interval, ha_config_count);

  if (connection.Init() == false)
  {
    ErrorHappened(&connection, &power, &logger);
  }
  logger.LogDebug("Success: connection.Init");

  if (connection.Connect(config[kDeviceConfigIndex].unique_id.c_str(), kWifiSsid, kWifiPassword, kMqttUser, kMqttPassword) == false)
  {
    ErrorHappened(&connection, &power, &logger);
  }
  logger.LogDebug("Success: connection.Connect");

  // only send HA config at first boot or after failed boot or in regular interval
  if (boot_count == 1 || failed_consecutive_boots > 0 || (kHaConfigInterval != 0 && ha_config_count >= kHaConfigInterval))
  {
    if (sensor->SendHomeassistantConfig() == false)
    {
      ErrorHappened(&connection, &power, &logger);
    }
    ha_config_count = 0;
  }
  ha_config_count++;

  if (sensor->SendHomeassistantState() == false)
  {
    ErrorHappened(&connection, &power, &logger);
  }

  EndWithNoError(&connection, &power, &logger);
}

// we use only setup() function
void loop() {}

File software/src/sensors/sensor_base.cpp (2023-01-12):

#include "sensor_base.h"

#include "battery_calculation.h"

SensorBase::SensorBase(ADC *adc, Connection *connection, Power *power, const char *readable_name, const char *unique_id, const char *sensor_name)
    : logger_(sensor_name), connection_(connection), power_(power), adc_(adc), last_battery_level_(100)
{
    ha_device_ = std::make_shared<SensorDevice>(readable_name, unique_id, "firebeetle32", "espressif");

    ha_voltage_ = std::make_shared<Sensor>("Akkuspannung", "voltage", SensorDeviceClass::kNone, "V", "mdi:battery-heart-variant");
    ha_device_->AddSensor(ha_voltage_);

    ha_battery_ = std::make_shared<Sensor>("Akkukapazität", "capacity", SensorDeviceClass::kBattery, "%");
    ha_device_->AddSensor(ha_battery_);

    ha_mode_ = std::make_shared<Sensor>("mode", "mode", SensorDeviceClass::kNone, "", "mdi:message-bulleted");
    ha_device_->AddSensor(ha_mode_);

    ha_boot_count_ = std::make_shared<Sensor>("boot_count", "boot_count", SensorDeviceClass::kNone, "", "mdi:bell-check");
    ha_device_->AddSensor(ha_boot_count_);

    ha_failed_boots_ = std::make_shared<Sensor>("failed_boots", "failed_boots", SensorDeviceClass::kNone, "", "mdi:bell-cancel");
    ha_device_->AddSensor(ha_failed_boots_);

    ha_max_readout_interval_ = std::make_shared<Sensor>("max_readout_interval", "max_readout_interval", SensorDeviceClass::kNone, "s", "mdi:bell-sleep");
    ha_device_->AddSensor(ha_max_readout_interval_);

    ha_config_count_ = std::make_shared<Sensor>("ha_config_count", "ha_config_count", SensorDeviceClass::kNone, "", "mdi:bell-ring");
    ha_device_->AddSensor(ha_config_count_);
}

bool SensorBase::SendHomeassistantConfig()
{
    for (const auto &message : ha_device_->GetAllConfigMessages())
    {
        if (connection_->Publish(message.GetTopic(), message.GetPayload()) == false)
        {
            logger_.LogError("Failed to publish config message to MQTT");
            return false;
        }

        logger_.LogInfo("Sent config message to: %s", message.GetTopic());
        logger_.LogInfo("  payload: %s", message.GetPayload());
    }

    return true;
}

bool SensorBase::SendHomeassistantState()
{
    const auto message = ha_device_->GetStateMessage();
    if (connection_->Publish(message.GetTopic(), message.GetPayload()) == false)
    {
        logger_.LogError("Failed to publish state message to MQTT");
        return false;
    }

    logger_.LogInfo("Sent state message to: %s", message.GetTopic());
    logger_.LogInfo("  payload: %s", message.GetPayload());

    return true;
}

bool SensorBase::SensorReadLoop()
{
    BatteryLoop();

    if (InternalPowerUp() == false)
    {
        logger_.LogError("Failed to wake up sensor");
        return false;
    }

    if (InternalSensorMeasurement() == false)
    {
        logger_.LogError("Failed to take sensor measurements");
        InternalPowerSave();
        InternalPowerDown();
        return false;
    }

    InternalPowerSave();

    if (InternalSensorRead() == false)
    {
        logger_.LogError("Failed to read sensor values");
        InternalPowerDown();
        return false;
    }

    InternalPowerDown();
    return true;
}

bool SensorBase::LowPower() const
{
    return last_battery_level_ < 10;
}

void SensorBase::SetDebugInfos(const char *mode, size_t boot_count, size_t failed_boots, std::chrono::seconds max_readout_interval, size_t ha_config_count)
{
    logger_.LogInfo("mode=%s", mode);
    ha_mode_->SetValue(mode);

    logger_.LogInfo("boot_count=%u", boot_count);
    ha_boot_count_->SetValue(boot_count, 0);

    logger_.LogInfo("failed_boots=%u", failed_boots);
    ha_failed_boots_->SetValue(failed_boots, 0);

    logger_.LogInfo("max_readout_interval=%llus", max_readout_interval.count());
    ha_max_readout_interval_->SetValue(max_readout_interval.count(), 0);

    logger_.LogInfo("ha_config_count=%u", ha_config_count);
    ha_config_count_->SetValue(ha_config_count, 0);
}

void SensorBase::BatteryLoop()
{
    const auto voltage = adc_->ReadVoltage();
    last_battery_level_ = BatteryCalculation::CapacityLevelPercent(voltage);
    ha_battery_->SetValue(last_battery_level_, 0);
    ha_voltage_->SetValue(voltage, 2);
}

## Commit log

2020-10-17 * auto discovery works with single sensor device
2020-10-17 working autodiscovery with VM and max MQTT message size
    need to replace mqtt library to correctly set message max payload:
    e.g. https://platformio.org/lib/search?query=pubsubclient
    [main.cpp]
2020-10-17 * prepare for multi value sensor
2020-10-17 * change to arduino String and allow multiple sensors per device
    # Conflicts:
    # src/main.cpp
2020-10-17 + add CO2 sensor with icon
2020-10-17 * replace MQTT library to work with big payloads
    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
    [main.cpp]
2020-10-17 r add error handling and change structure to setup() only
    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
    [main.cpp]
2020-10-17 + working battery level -> needs refactoring
2020-10-17 ~ extract SensorBase and ADC and BatteryCalculations
2020-10-17 ~ move responsibility of BatteryLoop into SensorBase
2020-10-17 * introduce Logger class and replace direct serial usage
    [adc.cpp, main.cpp, sensor_base.cpp]
2020-10-17 + add more power save options
2020-10-17 * introduce Led class
2020-10-17 ~ introduce Power class
2020-10-17 * completely change main loop to improve power consumption
2020-10-17 * make version of ArduinoJson more flexible
2020-10-17 * move SendHomeassistantState() into SensorBase
2020-11-07 ~ rename device_production to hardware subfolder
2020-11-11 ! fix output of read out interval in ErrorHappened
    [main.cpp]
2020-11-11 * do send HA config also after failed boot
    [main.cpp]
2020-11-11 * improve power save features of SensorBase
2020-11-11 + introduce SensorInterface
2020-11-11 * move creation of sensor into DeviceFactory and use config object
2020-11-11 - remove redundant/old error message for connection.Connect
    [main.cpp]
2020-11-11 * extract connection.Init() out of DeviceFactory
2020-11-11 ~ merge SensorInterface::InitHardware with SensorReadLoop
2020-11-11 ~ extract config parts in main.cpp and introduce device array
2020-12-02 * lower Battery low voltage to 3.3V
2020-12-02 * decrease ADC resolution to have less noise
    [main.cpp]
2020-12-02 + add debug info to SensorBase
2020-12-02 ! ensure trimed value string in Sensor::SetValue
2020-12-05 + add Sensor::SetCalibration
2020-12-21 + add light sleep and integrate Power class into SensorBase
2020-12-21 + add SensorInterface::HardwareInitialization(const
2020-12-21 ~ centralize log for debuging infos into SensorBase
2020-12-21 * change existing sensor to use SoftWire and their integrated library
2021-01-10 * increase readout interval to 2 minutes to increase battery lifetime
2021-01-10 * adapt config array to match only 6 sensors
2021-01-10 ! Scd30::InternalSensorMeasurement waits readout_interval_
    This should help to reduce error readouts because of not synced CPU and Sensor
2021-01-10 * increase max battery voltage because the charger goes to 4.2V
2021-01-10 * do only flash at initialization and not at error
    [main.cpp]
2021-01-10 * do not flash in Power::Reboot()
2021-01-10 + add datasheet of battery
2021-01-25 * meta sensor data should never expire
2021-01-25 + add mode string in debug info of sensor
2021-01-26 + add and change to SensorInterface::ForceCalibrationNow()
    Disable auto calibration
2021-01-29 + information/data for outdoor case
    [Boden.stl, Deckel.stl, Gehaeuse.f3z]
2021-02-01 + add note about heat dissipation of charging circuit
2021-02-01 + add note about 3D printing
2021-02-01 + add serial adapter driver
2023-08-28 ! do not incorporate the readable device name into the message name
    This is no longer allowed as of HA version 2023.08.
    See: https://developers.home-assistant.io/blog/2023-057-21-change-naming-mqtt-entities/
2024-01-10 + add long term statistics for the sensor values
2024-01-28 + add description for operation with power supply
2024-01-28 + add description for the usage of the CO2 auto calibration mode
2024-02-04 + add comment about typical SCD30 temperature offset values
2025-11-24 Add 5W USB-Micro power supply to hardware README
